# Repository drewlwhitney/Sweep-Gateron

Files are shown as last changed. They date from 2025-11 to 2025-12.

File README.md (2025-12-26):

[Head Repository](https://github.com/davidphilipbarr/Sweep)

# Sweep Gateron
sweep-gateron
<sub>Wireless Ferris Sweep with Gateron KS-33 switches and [Nyphy COAST Dawn](https://nuphy.com/collections/keycaps/products/coast-dawn-nsa?_pos=16&_fid=9b29c1ae1&_ss=c) keycaps</sub>

A modified Ferris Sweep for [Gateron KS-33 switches](https://www.gateron.co/products/gateron-low-profile-mechanical-switch-set) ([hotswap sockets](https://www.gateron.com/products/gateron-low-profile-switch-hot-swap-pcb-socket?VariantsId=10234) required).

## Variants
- [Basic](./Sweep-Gateron/) - MX spacing, based on the [Sweep High](https://github.com/davidphilipbarr/Sweep/tree/main/Sweep%20High).
- [JST](./Sweep-Gateron/jst/) - Same as the basic version, but the TRS jack is replaced with a 2-pin JST connector for the battery in wireless builds (and the reset button is moved). **Wireless only**.
- [JST-TRS](./Sweep-Gateron/jst-trs/) - Same as the basic version, but adds a 2-pin JST connector (for a battery) on top of the TRS jack. Can be used for wired *or* wireless builds.

All variants support a [switch plate](./Sweep-Gateron/switch-plate/) and [bottom plate](./Sweep-Gateron/bottom-plate/).

## Components
Unless otherwise stated, this Sweep uses the same components as the base Sweep.

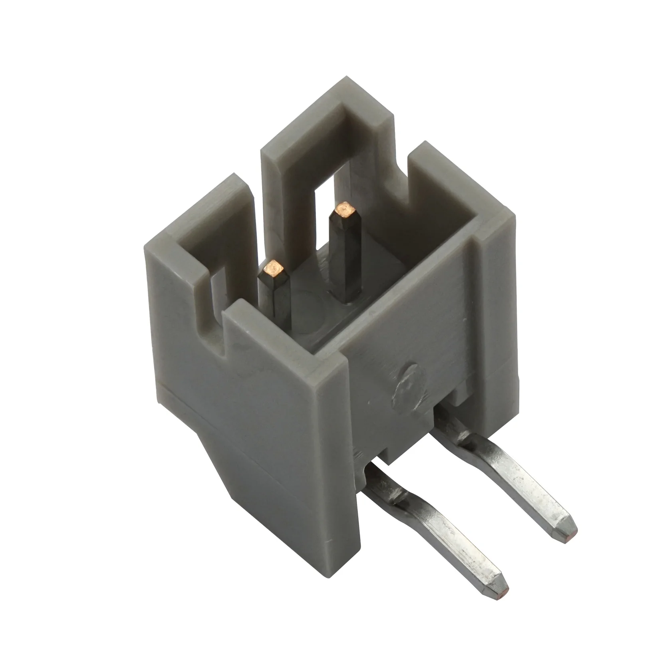
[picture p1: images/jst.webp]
jst
- The JST connector for the JST version is from [typeractive](https://typeractive.xyz/products/battery-jack).

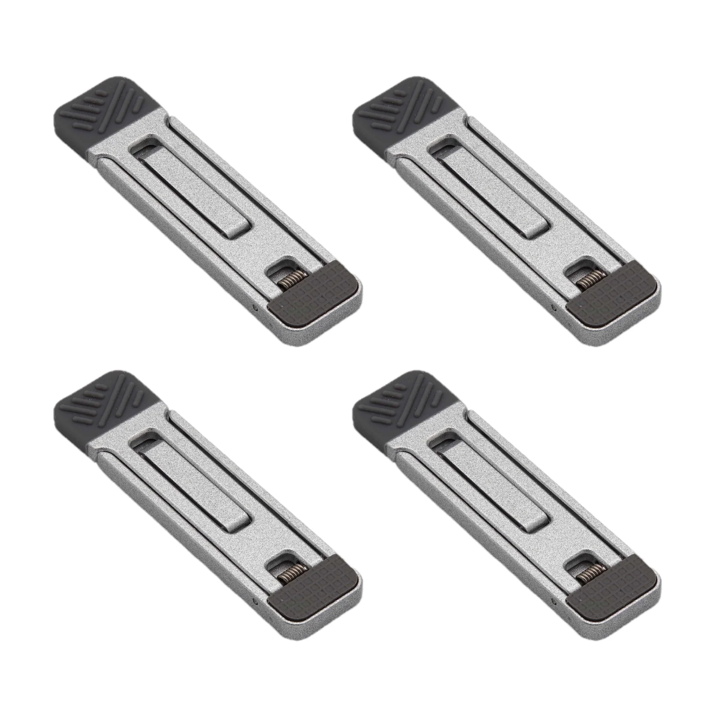
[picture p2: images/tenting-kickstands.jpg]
keckstands
- This board *does not* support a tenting puck, but great alternatives are tenting kickstands (from [typeractive](https://typeractive.xyz/products/battery-jack))
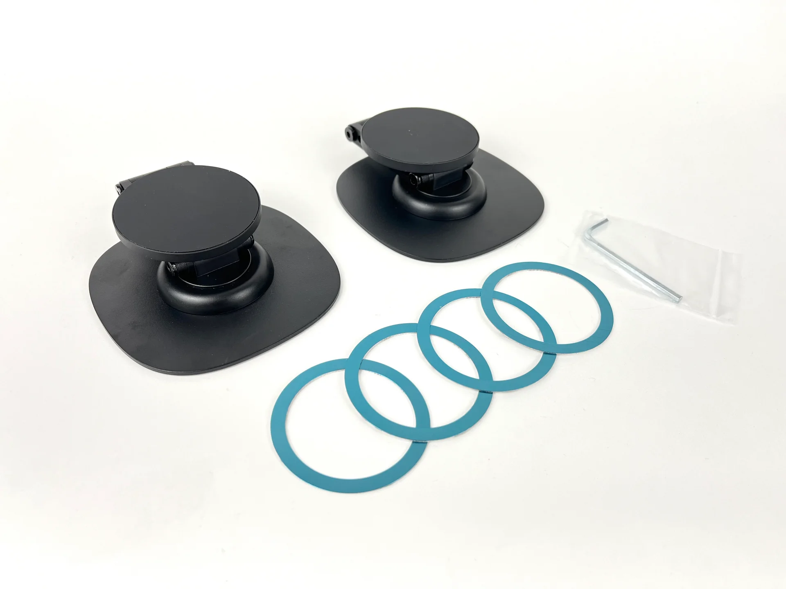
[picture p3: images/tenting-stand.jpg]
magsafe stands
 or MagSafe tenting stands (from [Keebio](https://keeb.io/products/magnetic-magsafe-tenting-stand-kit-for-split-keyboard-r2)).

## Gallery
### Front
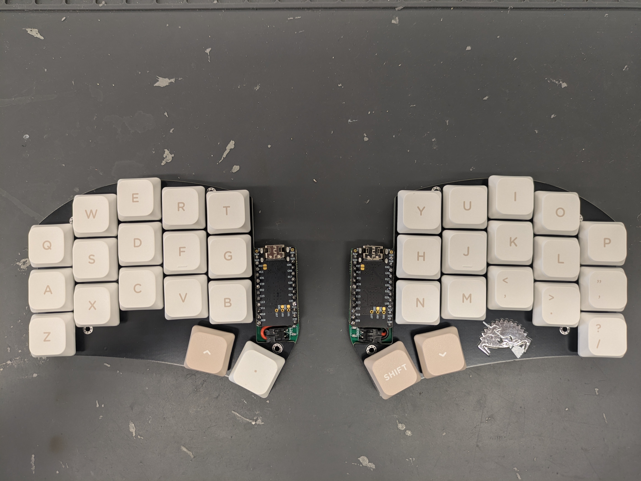
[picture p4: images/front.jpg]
front

### Back
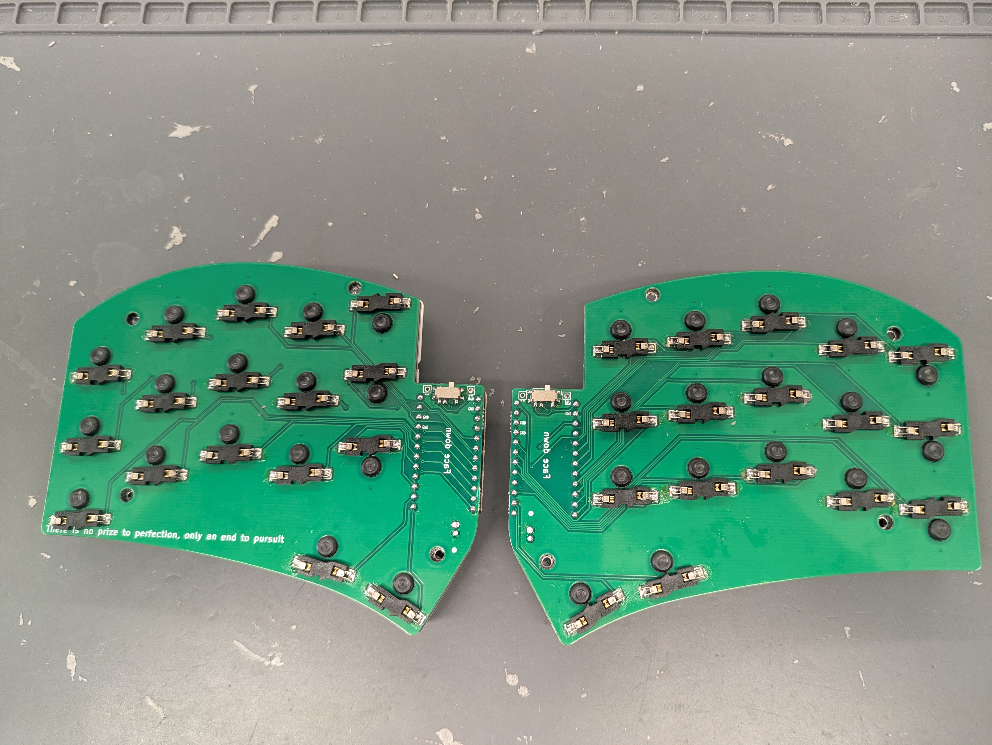
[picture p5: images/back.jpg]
back


## Notes
- If you edit this board, be aware that the schematic files are affected by [#75](https://github.com/davidphilipbarr/Sweep/issues/75). The PCB files are correct according to the software pinout, however, and will be manufactured correctly.

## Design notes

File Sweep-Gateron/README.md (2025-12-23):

# Sweep Gateron (Basic)
Sweep Gateron for wired or wireless builds.

## Build Instructions
See the [Sweep High](https://github.com/davidphilipbarr/Sweep/tree/main/Sweep%20Bling%20MX) folder for PCB manufacturing instructions.

### Gerber Files
Can be found [here](./gerber_to_order/).

### Switch Plate and Bottom Plate
Can be found [here](./switch-plate/) and [here](./bottom-plate/), respectively.

## Added Footprints
- [Hotswap KS-33](https://github.com/ai03-2725/MX_V2/tree/main/Gateron_KS33_Hotswap.pretty)

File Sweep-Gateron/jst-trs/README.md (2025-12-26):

# Sweep Gateron (JST-TRS)
Adds a 2-pin JST connector in the same position as the TRS connector. This can be used for wired or wireless builds. The JST connector can be purchased [here](https://typeractive.xyz/products/battery-jack).

## Build Instructions
See the [Sweep High](https://github.com/davidphilipbarr/Sweep/tree/main/Sweep%20Bling%20MX) folder for PCB manufacturing instructions.

### Gerber Files
Can be found [here](./gerber_to_order/).

### Switch Plate and Bottom Plate
Can be found [here](../switch-plate/) and [here](../bottom-plate/), respectively.

## Added Footprints
- [2-pin JST Connector](https://app.ultralibrarian.com/details/fbd6f894-563c-11ea-8c00-0ad2c9526b44/JST/S2B-PH-K-S-LF-SN-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)

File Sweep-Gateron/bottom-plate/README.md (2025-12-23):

Same as the [Sweep High](https://github.com/davidphilipbarr/Sweep/tree/main/Sweep%20Bling%20MX) bottom plate but without tenting puck support.

## Gerber Files
[Here](./gerber_to_order/)

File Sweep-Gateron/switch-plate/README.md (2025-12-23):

Same as the [Sweep High](https://github.com/davidphilipbarr/Sweep/tree/main/Sweep%20Bling%20MX) switch plate but without tenting puck support.

## Gerber Files
[Here](./gerber_to_order/)

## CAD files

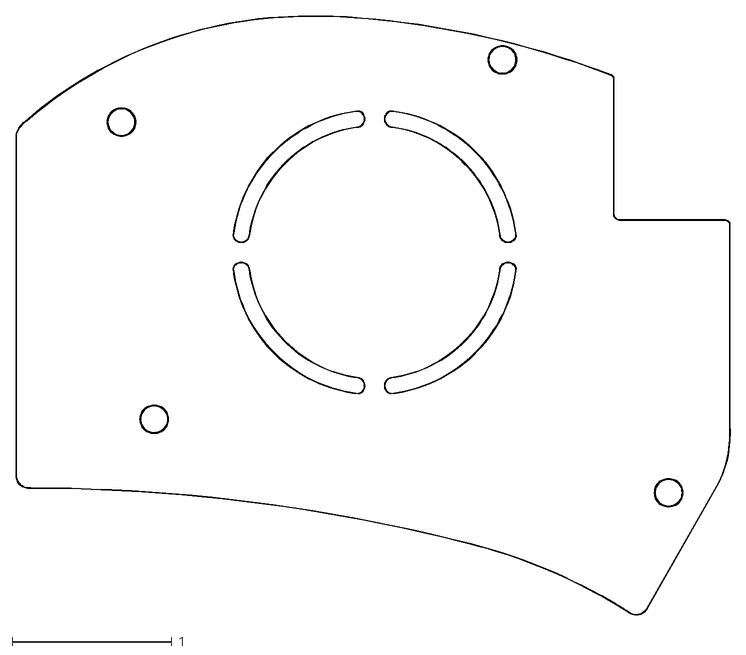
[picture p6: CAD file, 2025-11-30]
Sweep-Gateron/bottom-plate/sweep-gateron__bottom.dxf
4.47 x 3.75

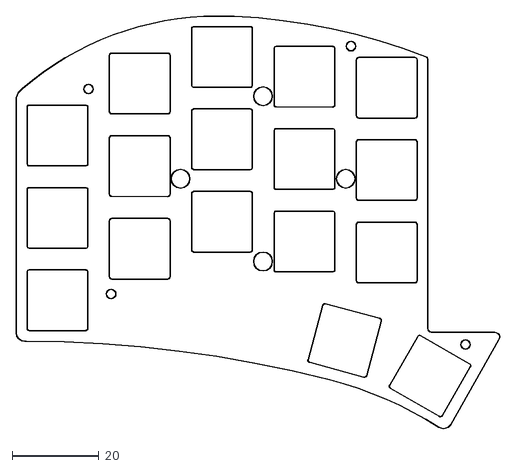
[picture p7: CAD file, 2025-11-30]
Sweep-Gateron/switch-plate/sweep-gateron__plate-Edge_Cuts.dxf
111.6 x 95.2

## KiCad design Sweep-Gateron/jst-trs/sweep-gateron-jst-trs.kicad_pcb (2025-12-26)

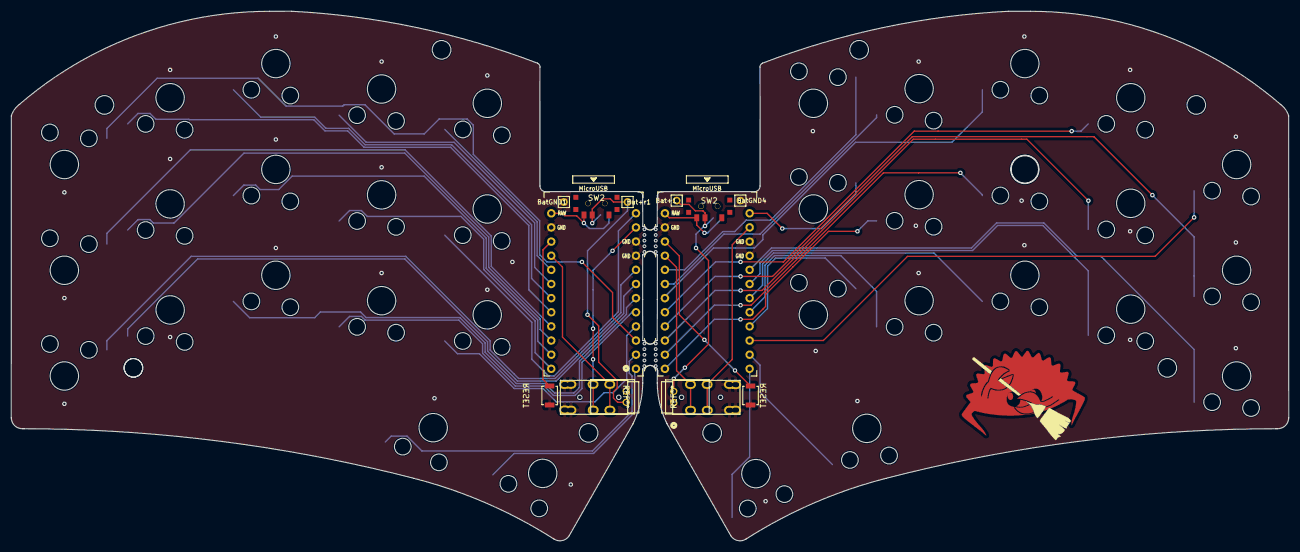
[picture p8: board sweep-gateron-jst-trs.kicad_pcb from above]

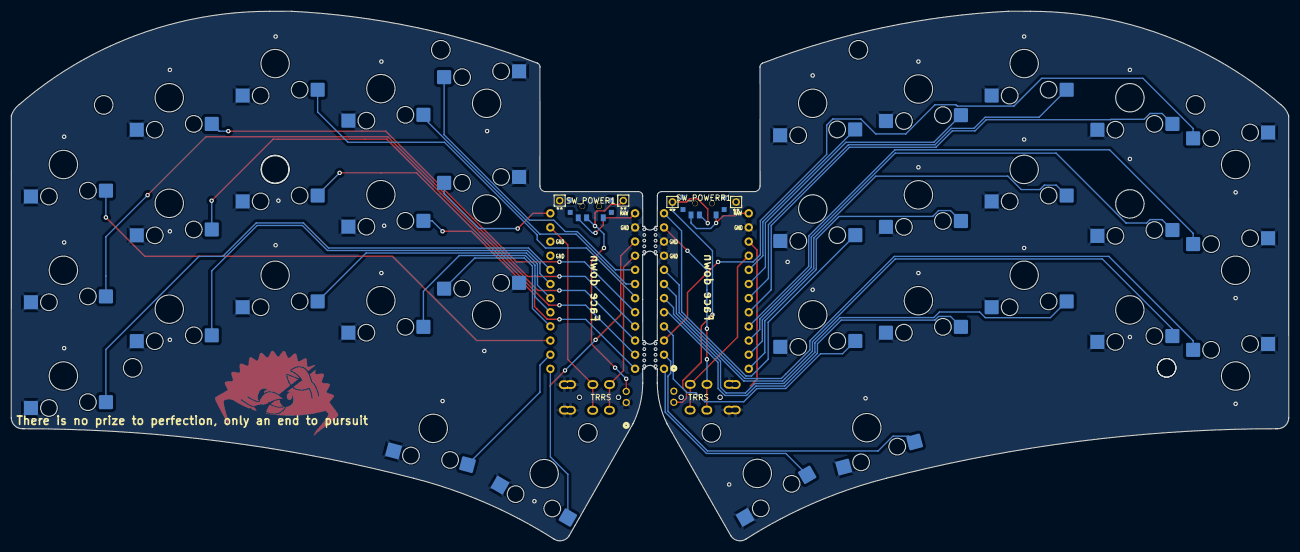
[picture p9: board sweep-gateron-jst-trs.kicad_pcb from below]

Board: 2 copper layers, 229.5 x 95.2 mm, 58 parts (40 on the bottom side), 43 nets.

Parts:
Bat+1: MountingHole_Pad; 1pin_conn
Bat+r1: MountingHole_Pad; 1pin_conn
BatGND1, BatGND4: MountingHole_Pad; 1pin_conn
J1, J2: AudioJack4dpb; TRRS-PJ-DPB2
Mounting 01, Mounting 01#2, Mounting 02, Mounting 02#2, Mounting 03, Mounting 03#2, Mounting 04, Mounting 04#2: MountingHole_3.35mm
RSW1, RSW2: SW_Push; SW_SPST_B3U-1000P
SW2, SW2#2: SW_SPDT; SPDT_C128955r
SW2#3, SW2_r1, SW3, SW3_r1, SW4, SW4_r1, SW5, SW5_r1, SW6, SW6_r1, SW7_r1, SW8, SW8_r1, SW9, SW9_r1, SW10, SW10_r1, SW11, SW11_r1, SW12, SW12_r1, SW13_r1, SW14, SW14_r1, SW15, SW15_r1, SW16, SW16_r1, SW17, SW18, SW20, SW20#2, SW21, SW21#2: SW_Push; Gateron-KS33-Hotswap-1U
SW_POWER1: SW_SPDT; SPDT_C128955
SW_POWERR1: SW_SPDT; SPDT_C128955
U1, U2: ProMicro-kbd; ProMicro_v3_min
mouse-bite-5mm-slot, mouse-bite-5mm-slot#2: VAL**; mouse-bite-5mm-slot-with-space-for-track

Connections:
BT+: Bat+1.1, SW2.2, SW_POWER1.2 (B)
BT+_r: Bat+r1.1, SW2#2.2, SW_POWERR1.2 (B)
Switch1: SW2#3.1, U1.10 (E6)
Switch1_r: SW2_r1.1, U2.10 (E6)
Switch2: SW3.1, U1.17 (F7)
Switch2_r: SW3_r1.1, U2.17 (F7)
Switch3: SW4.1, U1.18 (F6)
Switch3_r: SW4_r1.1, U2.18 (F6)
Switch4: SW5.1, U1.19 (F5)
Switch4_r: SW5_r1.1, U2.19 (F5)
Switch5: SW6.1, U1.20 (F4)
Switch5_r: SW6_r1.1, U2.20 (F4)
Switch6: SW8.1, U1.16 (B1)
Switch6_r: SW7_r1.1, U2.16 (B1)
Switch7: SW9.1, U1.15 (B3)
Switch7_r: SW8_r1.1, U2.15 (B3)
Switch8: SW10.1, U1.14 (B2)
Switch8_r: SW9_r1.1, U2.14 (B2)
Switch9: SW11.1, U1.13 (B6)
Switch9_r: SW10_r1.1, U2.13 (B6)
Switch10: SW12.1, U1.1 (TX)
Switch10_r: SW11_r1.1, U2.1 (TX)
Switch11: SW14.1, U1.5 (SDA)
Switch11_r: SW12_r1.1, U2.5 (SDA)
Switch12: SW15.1, U1.6 (SCL)
Switch12_r: SW13_r1.1, U2.6 (SCL)
Switch13: SW16.1, U1.7 (D4)
Switch13_r: SW14_r1.1, U2.7 (D4)
Switch14: SW17.1, U1.8 (C6)
Switch14_r: SW15_r1.1, U2.8 (C6)
Switch15: SW18.1, U1.9 (D7)
Switch15_r: SW16_r1.1, U2.9 (D7)
Switch16: SW20.1, U1.11 (B4)
Switch16_r: SW20#2.1, U2.11 (B4)
Switch17: SW21.1, U1.12 (B5)
Switch17_r: SW21#2.1, U2.12 (B5)
Switch18: J2.R1, U1.2 (RX)
Switch18_r: J1.R1, U2.2 (RX)
gnd: BatGND1.1, BatGND4.1, J1.S, J1.T, J2.S, J2.T, RSW1.1, RSW2.1, SW2#3.2, SW2_r1.2, SW3.2, SW3_r1.2, SW4.2, SW4_r1.2, SW5.2, SW5_r1.2, SW6.2, SW6_r1.2, SW7_r1.2, SW8.2, SW8_r1.2, SW9.2, SW9_r1.2, SW10.2, SW10_r1.2, SW11.2, SW11_r1.2, SW12.2, SW12_r1.2, SW13_r1.2, SW14.2, SW14_r1.2, SW15.2, SW15_r1.2, SW16.2, SW16_r1.2, SW17.2, SW18.2, SW20.2, SW20#2.2, SW21.2, SW21#2.2, U1.3 (GND), U1.4 (GND), U1.23 (GND), U2.3 (GND), U2.4 (GND), U2.23 (GND)
raw: SW2.3, SW2#2.3, SW_POWER1.3 (C), SW_POWERR1.3 (C), U1.24 (RAW), U2.24 (RAW)
reset: RSW1.2, U1.22 (RST)
reset_r: RSW2.2, U2.22 (RST)
vcc: J1.R2, J2.R2, U1.21 (VCC), U2.21 (VCC)

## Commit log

2025-11-30 Made a lot of progress routing the gateron pcb
    [ferris-sweep-compact.kicad_pcb, ferris-sweep-compact.sch, half-swept.kicad_pcb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]
2025-11-30 Routed the right side pcb
    [sweep-gateron.kicad_pcb]
2025-11-30 Making sure we're up to date
    [sweep-gateron.kicad_pcb]
2025-12-01 Had my friend look at the board, routing seems okay. Added some via stitches for better ground plane continuity
    [sweep-gateron.kicad_pcb]
2025-12-01 Renamed some of the plate files. Just need to create the gerber files now
    [sweep-gateron__bottom.dxf, sweep-gateron__bottom.kicad_pcb, sweep-gateron__plate-Edge_Cuts.dxf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]
2025-12-02 Added a version that replaces the TRRS connector with a JST connector for wireless builds
    [sweep-gateron-jst.kicad_pcb, sweep-gateron-jst.kicad_sch]
2025-12-02 Added gerber files
    [sweep-gateron-jst.kicad_pcb, sweep-gateron.kicad_pcb, sweep-gateron__plate.kicad_pcb]
2025-12-23 Fixed swapped pads and generated gerber files
    [sweep-gateron-jst.kicad_pcb, sweep-gateron.kicad_pcb]
2025-12-23 Built the board and updated the documentation
2025-12-23 Changed the name of the Sweep Gateron folder to fix link issues in the docs
    [sweep-gateron-jst.kicad_pcb, sweep-gateron-jst.kicad_sch, sweep-gateron.kicad_pcb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]
2025-12-23 Added the missing gerber files
2025-12-26 Added a JST version that also has a TRS jack so you can order one board for both wired and wireless builds
    [sweep-gateron-jst-trs.kicad_pcb, sweep-gateron-jst-trs.kicad_sch]
